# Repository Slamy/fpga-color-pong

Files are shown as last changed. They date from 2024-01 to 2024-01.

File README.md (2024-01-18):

# FPGA Color Pong

This project aims to interpret the classic game of Pong in color using composite video. PAL, NTSC and SECAM can be used.
For input an Atari Paddle controller (1 MOhm Poti) is required.
The target plattform is the Tang Nano 9k but it should be portable to other plattforms as well.

This design is based on my [Composite Video Encoder](https://github.com/Slamy/fpga-composite-video) which handles the video generation.

## How to play

* Switch 2 of the Tang Nano will restart the game.
* Switch 1 cycles the supported video norms.
* Score 10 times to win the game.

## Schematic

Schematic of Video DAC and Paddle connection

## Screenshots and Photos

Example setup on a bread board.

Photo of breadboard

### PAL

VLC screenshot of PAL picture

### NTSC

VLC screenshot of NTSC picture

### SECAM

VLC screenshot of SECAM picture

SECAM currently suffers under "SECAM fire". I'm not able to fix that at the moment.

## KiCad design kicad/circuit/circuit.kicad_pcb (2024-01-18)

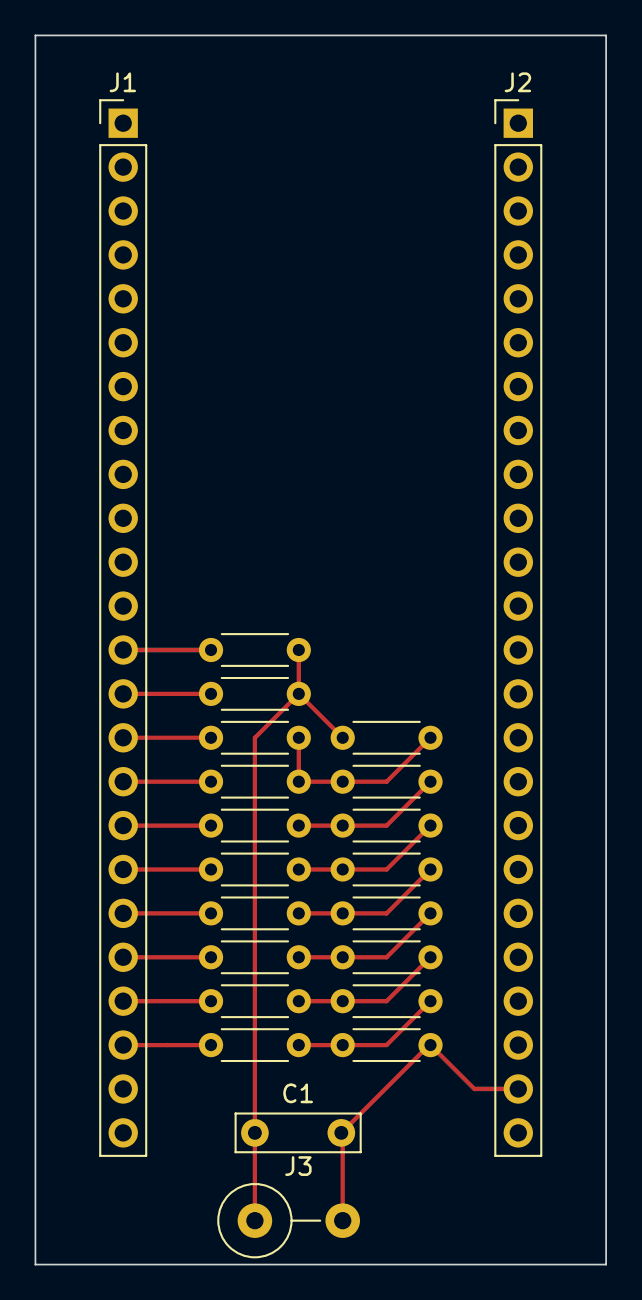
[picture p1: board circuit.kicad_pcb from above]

Board: 2 copper layers, 33.0 x 71.1 mm, 22 parts (0 on the bottom side), 19 nets.

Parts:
C1: C; C_Rect_L7.0mm_W2.0mm_P5.00mm
J1, J2: Conn_01x24; PinHeader_1x24_P2.54mm_Vertical
J3: Conn_Coaxial; L_Axial_L9.5mm_D4.0mm_P5.08mm_Vertical_Fastron_SMCC
R1, R2, R3, R4, R5, R6, R7: 240; R_Axial_DIN0204_L3.6mm_D1.6mm_P5.08mm_Horizontal
R8, R17, R18, R19: 470; R_Axial_DIN0204_L3.6mm_D1.6mm_P5.08mm_Horizontal
R9, R10, R11, R12, R14, R15, R16: 120; R_Axial_DIN0204_L3.6mm_D1.6mm_P5.08mm_Horizontal

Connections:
GND: C1.2, J2.23, J3.2 (Ext), R1.1
unnamed: J1.13, R19.2
unnamed: J1.14, R17.2
unnamed: J1.15, R18.2
unnamed: J1.16, R8.2
unnamed: J1.17, R7.2
unnamed: J1.18, R6.2
unnamed: J1.19, R5.2
unnamed: J1.20, R4.2
unnamed: J1.21, R3.2
unnamed: J1.22, R2.2
unnamed: C1.1, J3.1 (In), R14.1, R17.1, R19.1
unnamed: R1.2, R2.1, R9.2
unnamed: R4.1, R10.1, R12.2
unnamed: R3.1, R9.1, R10.2
unnamed: R6.1, R11.1, R16.2
unnamed: R5.1, R11.2, R12.1
unnamed: R8.1, R14.2, R15.1, R18.1
unnamed: R7.1, R15.2, R16.1

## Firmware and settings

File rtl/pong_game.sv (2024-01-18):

module pong_game (
    input clk,
    input reset,
    input [8:0] video_y,
    input [12:0] video_x,
    input [8:0] v_active,
    input newline,
    input newframe,
    input visible_window,
    input newpixel,
    input [7:0] paddle0,
    input [7:0] paddle1,
    input paddle0_button,
    input paddle1_button,
    output ycbcr_t ycbcr_out
);
    wire signed [9:0] last_row = v_active - 1;

    bit signed  [9:0] pixel_x = 0;
    bit signed  [9:0] pixel_y = 0;

    always_ff @(posedge clk) begin
        if (newline) pixel_x <= 0;
        if (visible_window && newpixel) pixel_x <= pixel_x + 1;

        pixel_y <= video_y - 38;
    end

    bit signed [9:0] paddle0_frame_latched_val;
    bit signed [9:0] paddle1_frame_latched_val;

    bit [7:0] R_d;
    bit [7:0] G_d;
    bit [7:0] B_d;

    always_ff @(posedge clk) begin
        rgb_conv_in.r <= R_d;
        rgb_conv_in.g <= G_d;
        rgb_conv_in.b <= B_d;

        if (video_y == 7) begin
            paddle0_frame_latched_val <= 10'(paddle0);
            paddle1_frame_latched_val <= 10'(paddle1);
        end
    end

    ycbcr_t rgb_conv_out;
    rgb_t   rgb_conv_in;
    RGB2YCbCr rgb_conv (
        .clk,
        .in (rgb_conv_in),
        .out(rgb_conv_out)
    );

    // Game logic
    typedef struct {
        bit signed [9:0] x;
        bit signed [9:0] y;
    } position_t;

    position_t ball;
    position_t ball_delay1;
    position_t ball_delay2;

    initial begin
        ball.x = 100;
        ball.y = 100;
    end
    delayfifo32e #(20) d1 (
        .clk,
        .enable(newframe),
        .in({ball.x, ball.y}),
        .latency(5),
        .out({ball_delay1.x, ball_delay1.y})
    );

    delayfifo32e #(20) d2 (
        .clk,
        .enable(newframe),
        .in({ball_delay1.x, ball_delay1.y}),
        .latency(5),
        .out({ball_delay2.x, ball_delay2.y})
    );

    bit signed [9:0] ball_speed_x = 1;
    bit signed [9:0] ball_speed_y = 0;
    bit signed [9:0] next_ball_speed_x;
    bit signed [9:0] next_ball_speed_y;
    //bit signed [9:0] nextball_speed_y = 1;
    localparam bit signed [9:0] ShadowX = 3;
    localparam bit signed [9:0] ShadowY = 4;

    localparam bit signed [9:0] BallHalfWidth = 3;
    localparam bit signed [9:0] BallHalfHeight = 5;

    localparam bit signed [9:0] PaddleHalfHeight = 30;

    bit signed [9:0] paddle_collider_top;
    bit signed [9:0] paddle_collider_bottom;
    bit signed [9:0] paddle_collision_force_d;
    bit signed [9:0] paddle_collision_force_q;

    always_ff @(posedge clk) paddle_collision_force_q <= paddle_collision_force_d;

    bit left_player_scored = 0;
    bit left_player_scored_q = 0;
    bit right_player_scored = 0;
    bit restart_game = 0;

    bit [3:0] left_player_score = 0;
    bit [3:0] right_player_score = 0;
    bit [7:0] charline;
    bit [7:0] charline_shadow;
    bit [7:0] ball_hit_cnt = 0;

    wire signed [9:0] pixel_x_shifted8 = pixel_x + 8;
    wire signed [9:0] pixel_x_shifted6 = pixel_x + 6;  // for shadow
    wire signed [9:0] pixel_y_shiftedM5 = pixel_y - 5;
    wire signed [9:0] pixel_y_shiftedM8 = pixel_y - 8;  // for shadow

    character_rom crom (
        .number(pixel_x > 128 ? right_player_score : left_player_score),
        .line  (pixel_y_shiftedM5[4:2]),
        .charline
    );

    character_rom crom_shadow (
        .number(pixel_x > 128 ? right_player_score : left_player_score),
        .line(pixel_y_shiftedM8[4:2]),
        .charline(charline_shadow)
    );


    always_comb begin
        if (ball.x > 128) begin
            paddle_collider_top = paddle1_frame_latched_val - PaddleHalfHeight;
            paddle_collider_bottom = paddle1_frame_latched_val + PaddleHalfHeight;
            // as >>>4 divides by 16, I'm adding 8 here for proper rounding
            paddle_collision_force_d = (ball.y - paddle1_frame_latched_val);
        end else begin
            paddle_collider_top = paddle0_frame_latched_val - PaddleHalfHeight;
            paddle_collider_bottom = paddle0_frame_latched_val + PaddleHalfHeight;
            // as >>>4 divides by 16, I'm adding 8 here for proper rounding
            paddle_collision_force_d = (ball.y - paddle0_frame_latched_val);
        end

    end

    always_comb begin
        next_ball_speed_x = 2;
        if (ball_hit_cnt > 0) next_ball_speed_x = 3;
        if (ball_hit_cnt > 1) next_ball_speed_x = 4;
        if (ball_hit_cnt > 2) next_ball_speed_x = 5;
        if (ball_hit_cnt > 3) next_ball_speed_x = 6;
        if (ball_hit_cnt > 10) next_ball_speed_x = 7;

        next_ball_speed_y = ((paddle_collision_force_q * next_ball_speed_x) + (1 << 3)) >>> 4;

        // limit ball to 45 degree angle
        if (next_ball_speed_y > next_ball_speed_x) next_ball_speed_y = next_ball_speed_x;
        else if (next_ball_speed_y < -next_ball_speed_x) next_ball_speed_y = -next_ball_speed_x;

        if (ball_speed_x > 0) next_ball_speed_x = -next_ball_speed_x;

    end

    always_ff @(posedge clk) begin
        // We need to sync the game logic to the frames. At first I didn't want to do this
        // to be independent of 60 and 50 Hz. But it simply doesn't work as screen tearing or jitter will occur.
        if (newframe) begin
            ball.x <= ball.x + ball_speed_x;
            ball.y <= ball.y + ball_speed_y;

            // paddle collision
            if (ball.y >= paddle_collider_top && ball.y <= paddle_collider_bottom) begin
                if (ball.x > (255 - 20) && ball.x < (255 - 12) && ball_speed_x > 0) begin
                    ball_speed_x <= next_ball_speed_x;
                    ball_speed_y <= next_ball_speed_y;
                    if (ball_hit_cnt != 255) ball_hit_cnt <= ball_hit_cnt + 1;
                end
                if (ball.x < 20 && ball.x > 12 && ball_speed_x < 0) begin
                    ball_speed_x <= next_ball_speed_x;
                    ball_speed_y <= next_ball_speed_y;
                    if (ball_hit_cnt != 255) ball_hit_cnt <= ball_hit_cnt + 1;
                end
            end

            // vertical collision
            if (ball.y < BallHalfHeight && ball_speed_y < 0) ball_speed_y <= -ball_speed_y;
            if (ball.y > last_row - BallHalfHeight && ball_speed_y > 0)
                ball_speed_y <= -ball_speed_y;

            // ball out of bounds
            if (ball.x > 255 + 5) left_player_scored <= 1;
            if (ball.x < -5) right_player_scored <= 1;

        end

        if (left_player_scored || right_player_scored) begin
            left_player_scored <= 0;
            right_player_scored <= 0;
            left_player_scored_q <= left_player_scored;
            restart_game <= 1;

            if (left_player_scored) left_player_score <= left_player_score + 1;
            else right_player_score <= right_player_score + 1;
        end

        if (restart_game) begin
            restart_game <= 0;
            ball.x <= 128;
            ball.y <= 128;
            ball_hit_cnt <= 0;
            ball_speed_y <= 0;
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

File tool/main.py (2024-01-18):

import math
import os
import struct

import serial
import serial.threaded
import matplotlib.pyplot as plt

serial = serial.Serial()
serial.port = "/dev/serial/by-id/usb-SIPEED_JTAG_Debugger_FactoryAIOT_Pro-if01-port0"
serial.baudrate = 3000000
serial.timeout = 1
serial.open()

# TODO For some reason the serial port only works after the second open.
# This problem correlates with the baud rate. With 115200 I don't have this issue
# This might be a linux only problem? Requires check on another operation system.
serial.close()
serial.open()

values = []
for _ in range(6000):
    arr = serial.read()
    values.append(struct.unpack("B", arr)[0])


plt.plot(values, 'g', label='value')
plt.show()
